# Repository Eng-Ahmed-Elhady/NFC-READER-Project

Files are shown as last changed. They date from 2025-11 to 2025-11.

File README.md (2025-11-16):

🚀 Project Overview – NFC Reader System (Custom 4-Layer Design)

This project was a full hardware development challenge combining power electronics, RF design, embedded control, and EMI/EMC-aware PCB layout.
A special thanks to Altium Academy and Zach — I learned a lot from their content, and it greatly improved the quality of this design.
Proud to say the system is now fully functional, reliable, and ready for integration.














⚡ 1. Power Architecture

The system receives a 24V input and regulates it down efficiently using:

Buck-Boost Converter

Buck Regulator

LDO

Each stage was selected to ensure stable output voltage, low ripple, and clean power delivery to all RF and MCU circuits.

🧠 2. Processing Unit – ESP32

The ESP32 acts as the main controller:

Communicates with the TRF7970A NFC Reader over SPI

Provides external UART interfaces through a dedicated connector

Integrated RESET and BOOT push buttons for convenient programming and debugging

Signal routing and isolation designed for optimal noise immunity

📡 3. NFC / RFID RF Section

A complete RF schematic was designed, including:

Antenna Matching Network

Tuning Circuit

TRF7970A Main RFID Circuit

The RF path was carefully engineered with controlled impedance and proper return-current handling.

🔧 4. External Control & Outputs

The board includes:

Relay driver for controlling an external motor

Input for an external push button

External status LED outputs

Motor activation only occurs after a valid ID is detected

🖥️ PCB Design – 4-Layer Professional Layout

Designed using Altium Designer, following strict high-performance hardware design rules:

Hierarchical schematic structure for clarity and maintenance

Proper track width and spacing for both power and RF routing

Full controlled-impedance profiles, calculated based on the official JLC04161H-3313 stackup

Crystal guard ring with no routing underneath to eliminate EMI coupling

Close placement of decoupling capacitors on every IC power pin

RF ground isolated from power ground, connected at a single defined point

Ground polygon pours and stitching vias to minimize return-current loops

Minimum 3× trace-width spacing between parallel traces to prevent crosstalk

Full compatibility with JLCPCB manufacturing rules and component sourcing from LCSC

All symbols and footprints were created directly from their datasheets

Proper thermal relief and heat-spreading areas for power regulators

Performed comprehensive ERC (Electrical Rule Check) and DRC (Design Rule Check) to ensure the design is error-free and manufacturing-ready

🎯 Final Result

A fully integrated, high-performance NFC Reader offering:
✔ Stable and reliable operation
✔ Clean and accurate RF behavior
✔ Excellent noise immunity
✔ Manufacturing-ready 4-layer layout
✔ Easy integration into larger embedded systems

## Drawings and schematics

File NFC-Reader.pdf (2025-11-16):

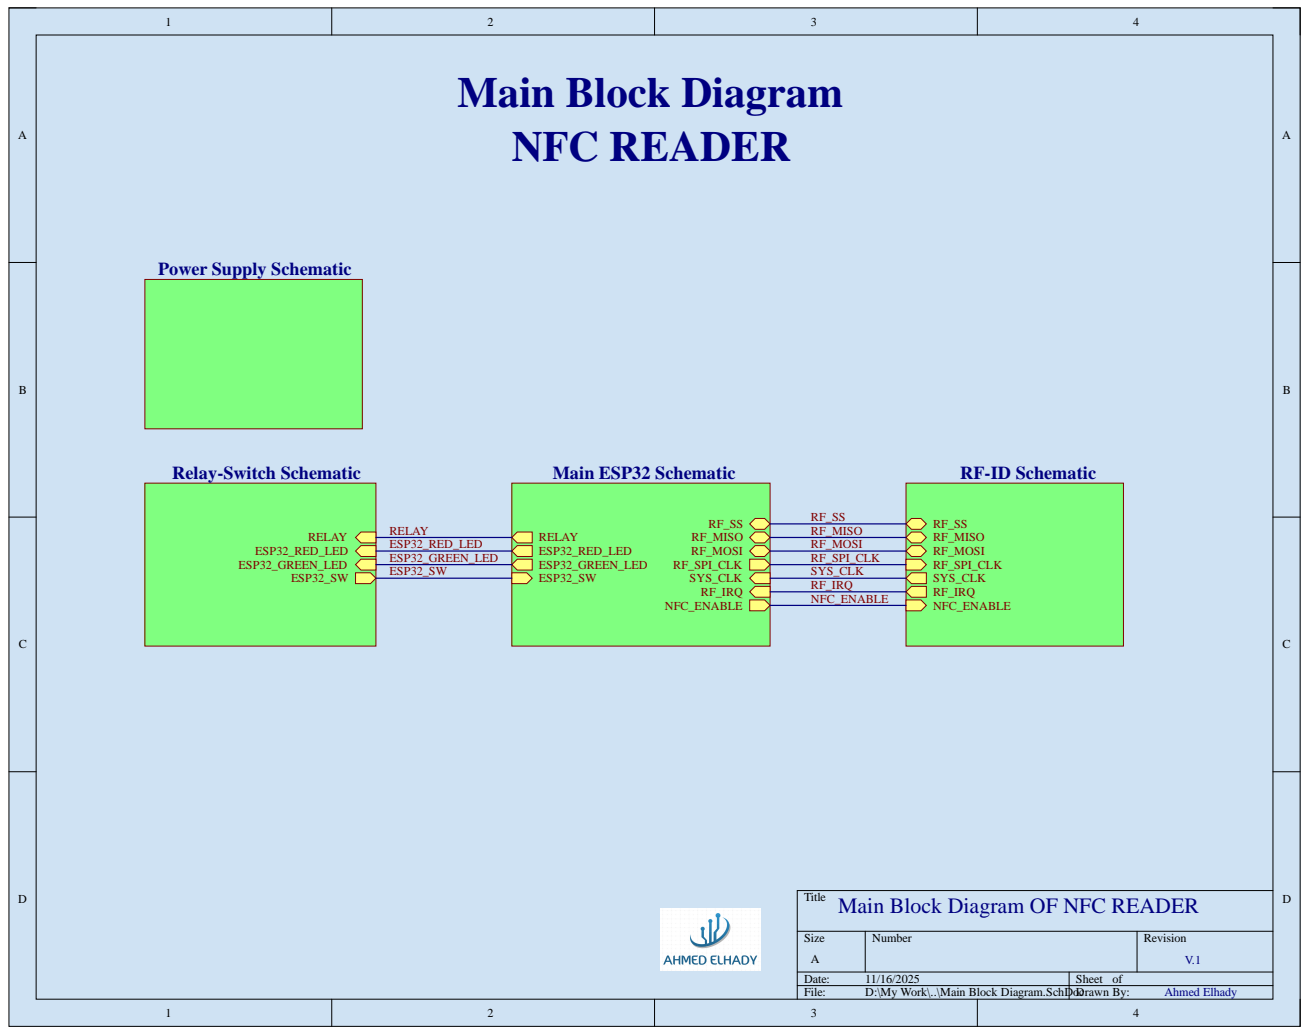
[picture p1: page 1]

E S P32_RE D_L E D | RF_M O S I
E S P32_GRE E N_L E D | RF_S PI_CL K
E S P32_S W | S Y S_CL K

Main Block Diagram OF NFC READER Ahmed

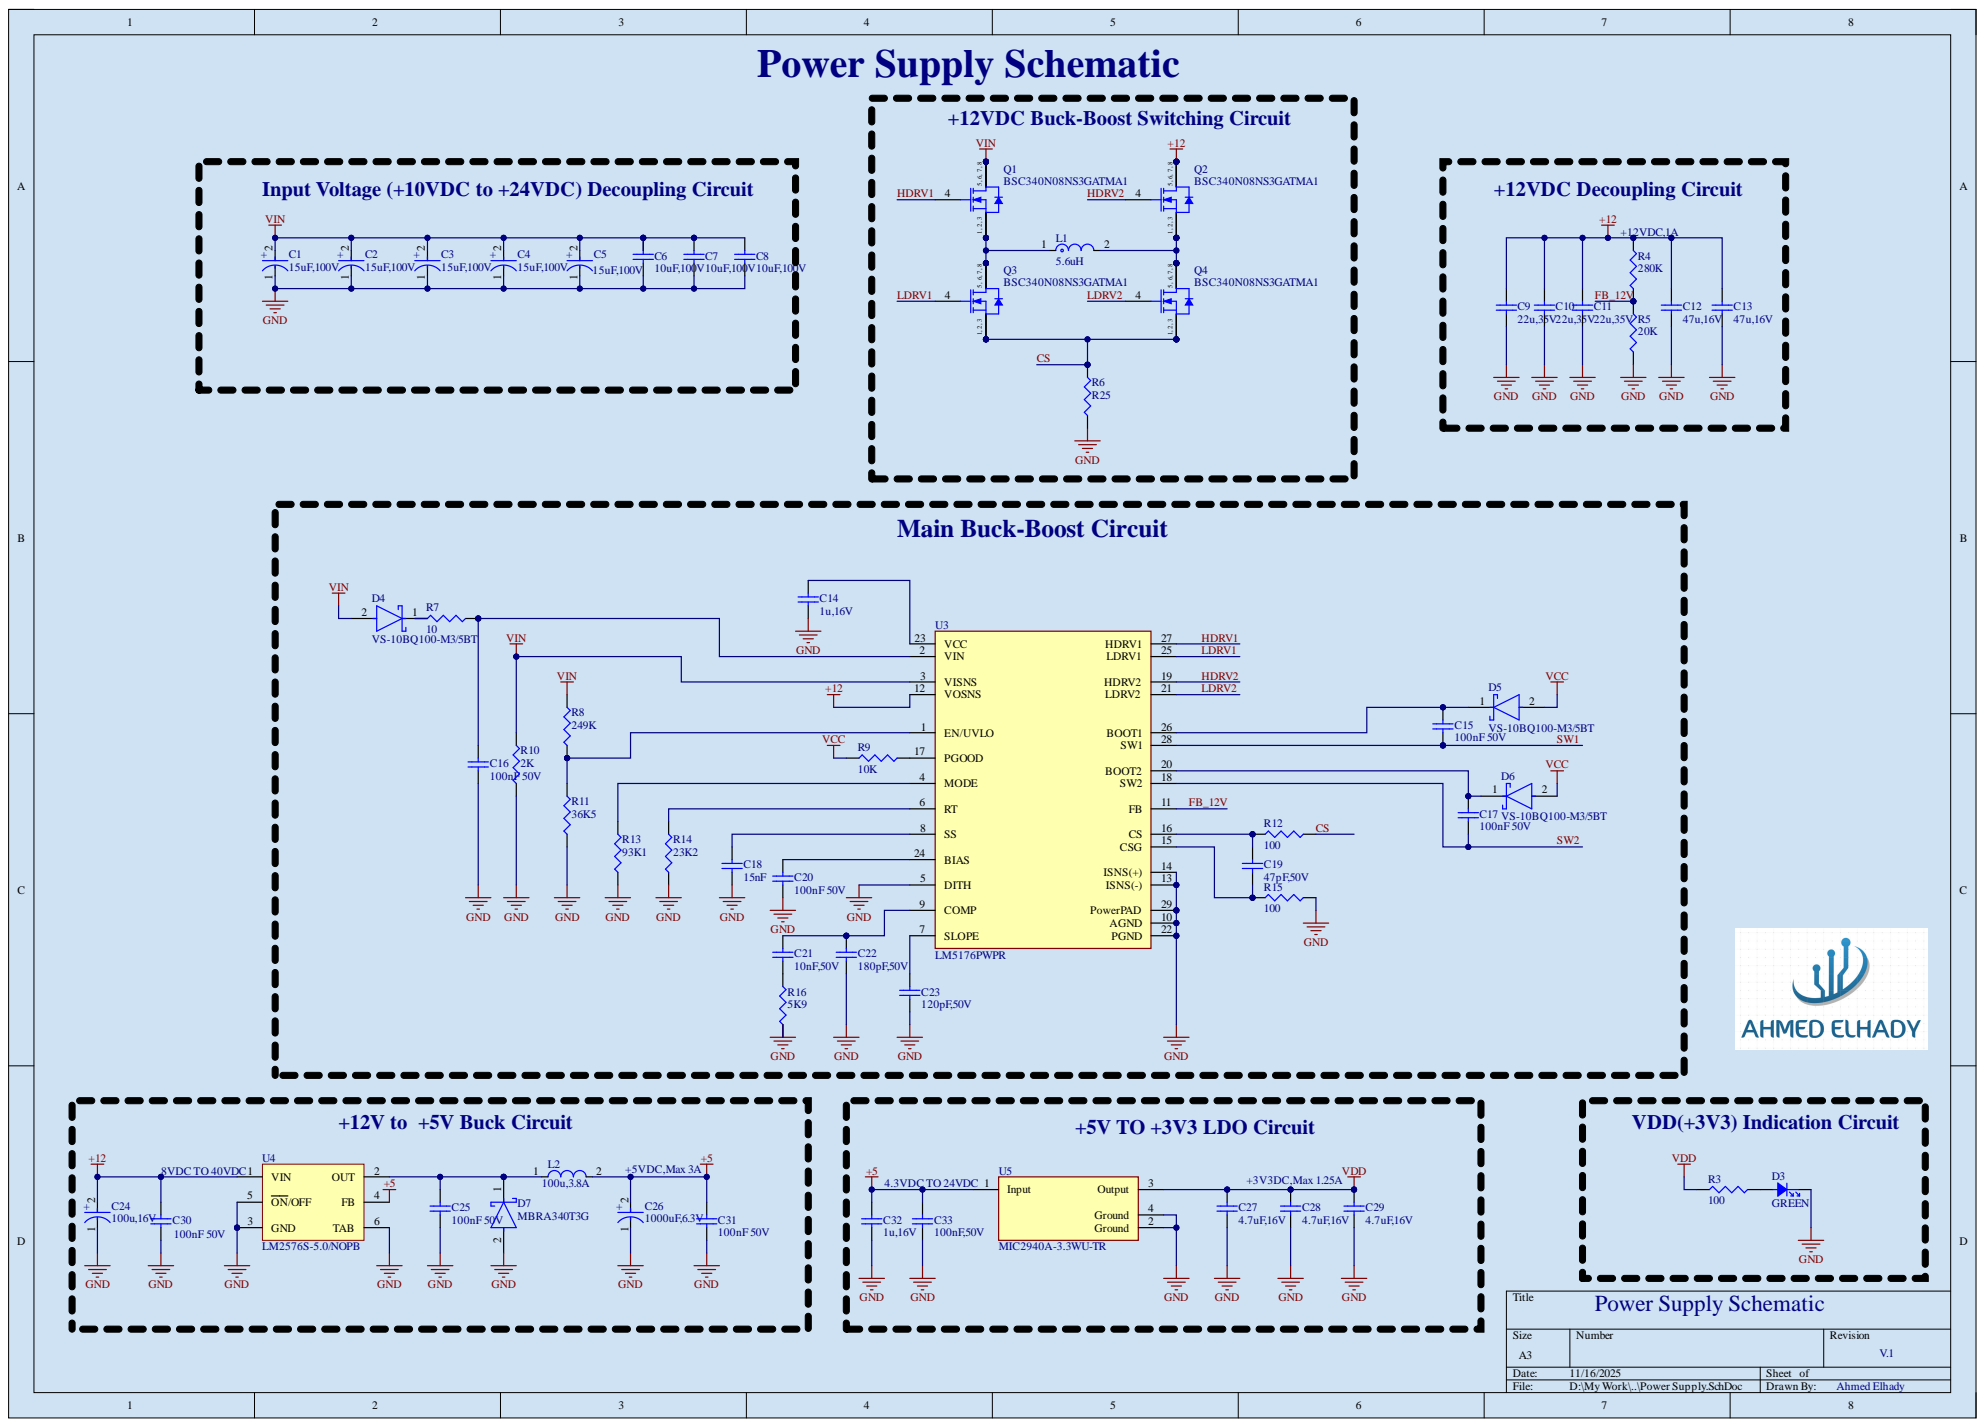
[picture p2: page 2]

+12VDC Buck-Boost Switching Circuit

Main Buck-Boost Circuit

VIN | | VISNS 3
+12 R8 249K | VOSNS 12 | LDRV2

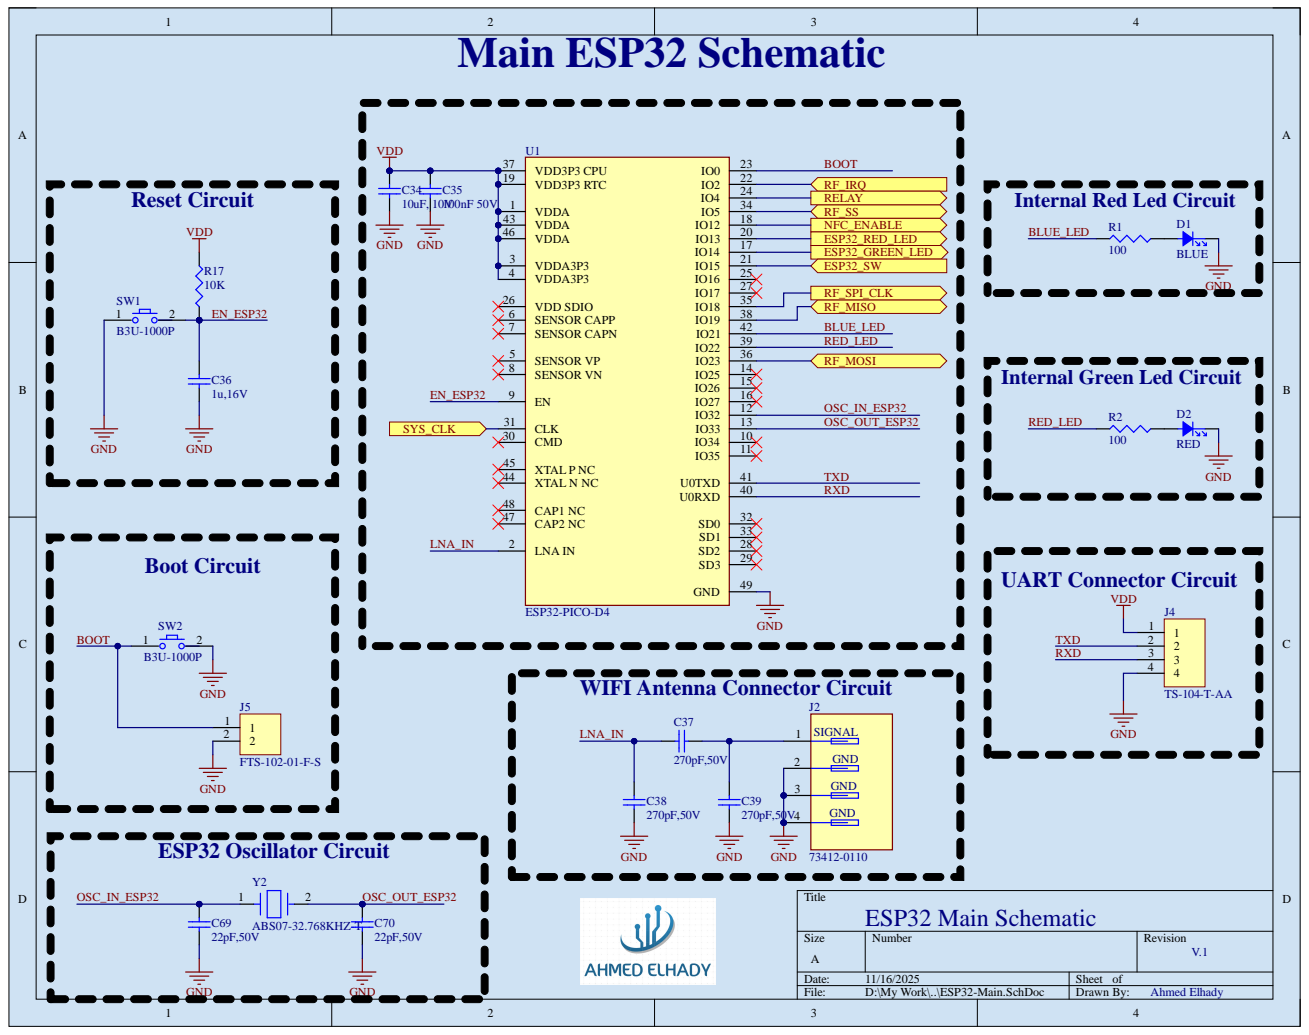
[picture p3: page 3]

Internal Red Led Circuit

Internal Green Led Circuit

WIFI Antenna Connector Circuit

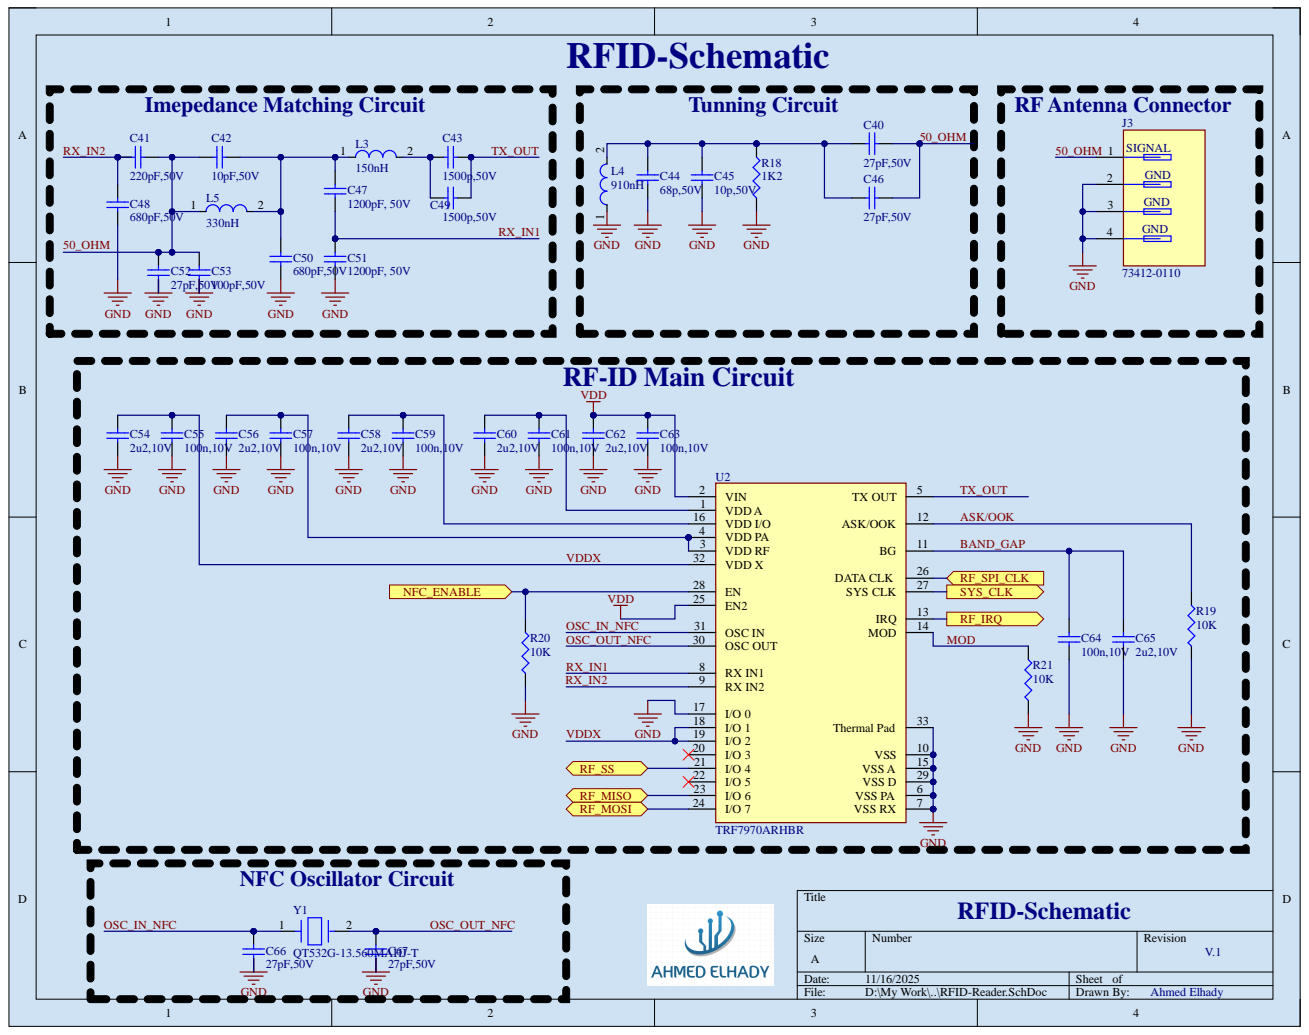
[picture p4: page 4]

RF-ID Main Circuit

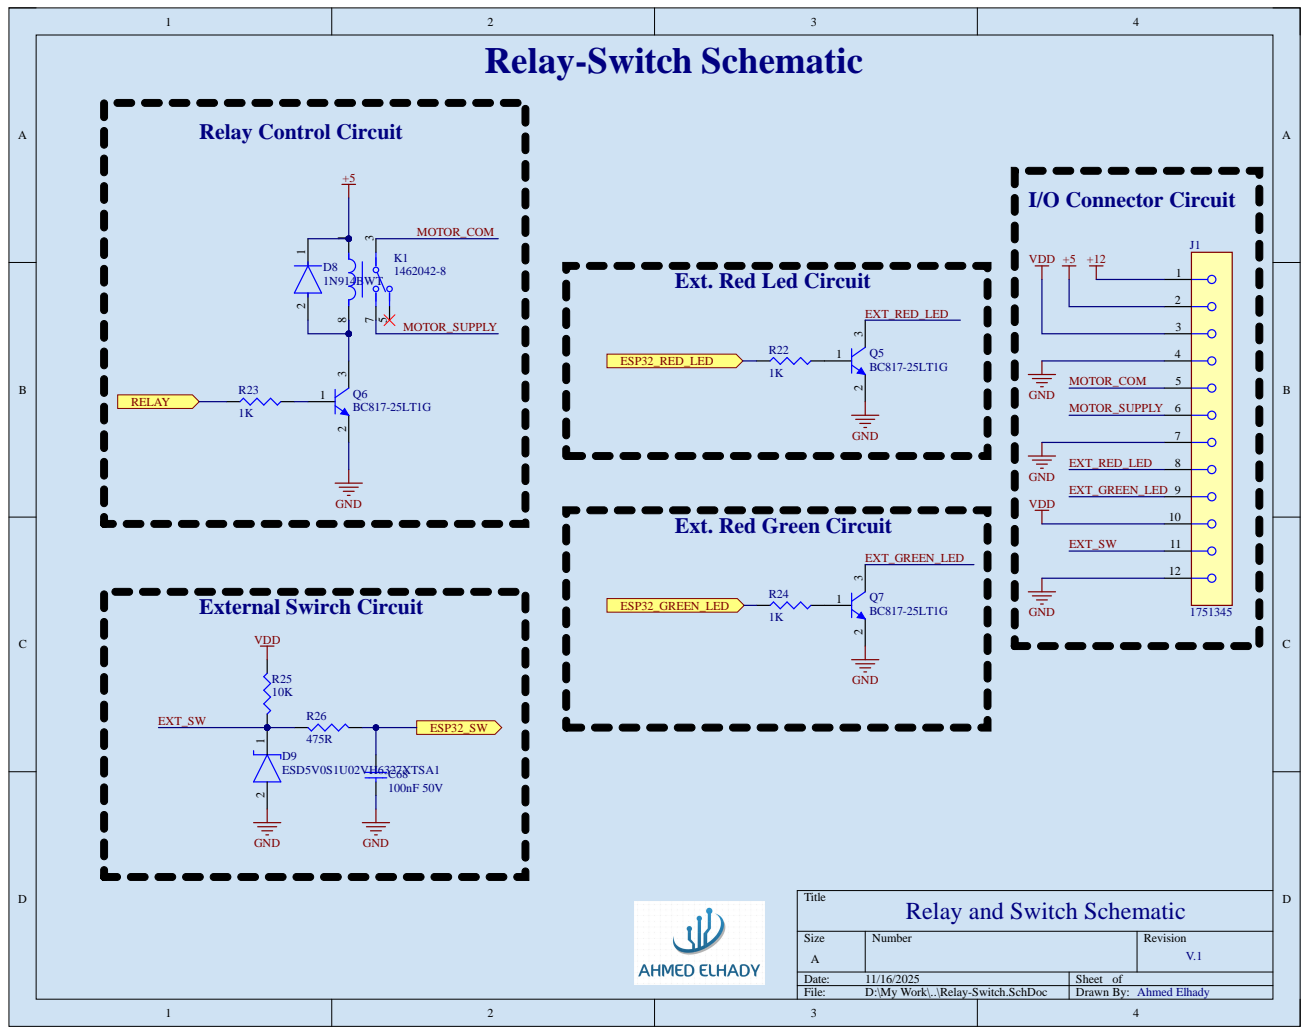
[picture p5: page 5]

Relay-Switch Schematic
I/O Connector Circuit Ahmed Elhady

Ext. Red Led Circuit

Ext. Red Green Circuit

Relay and Switch Schematic

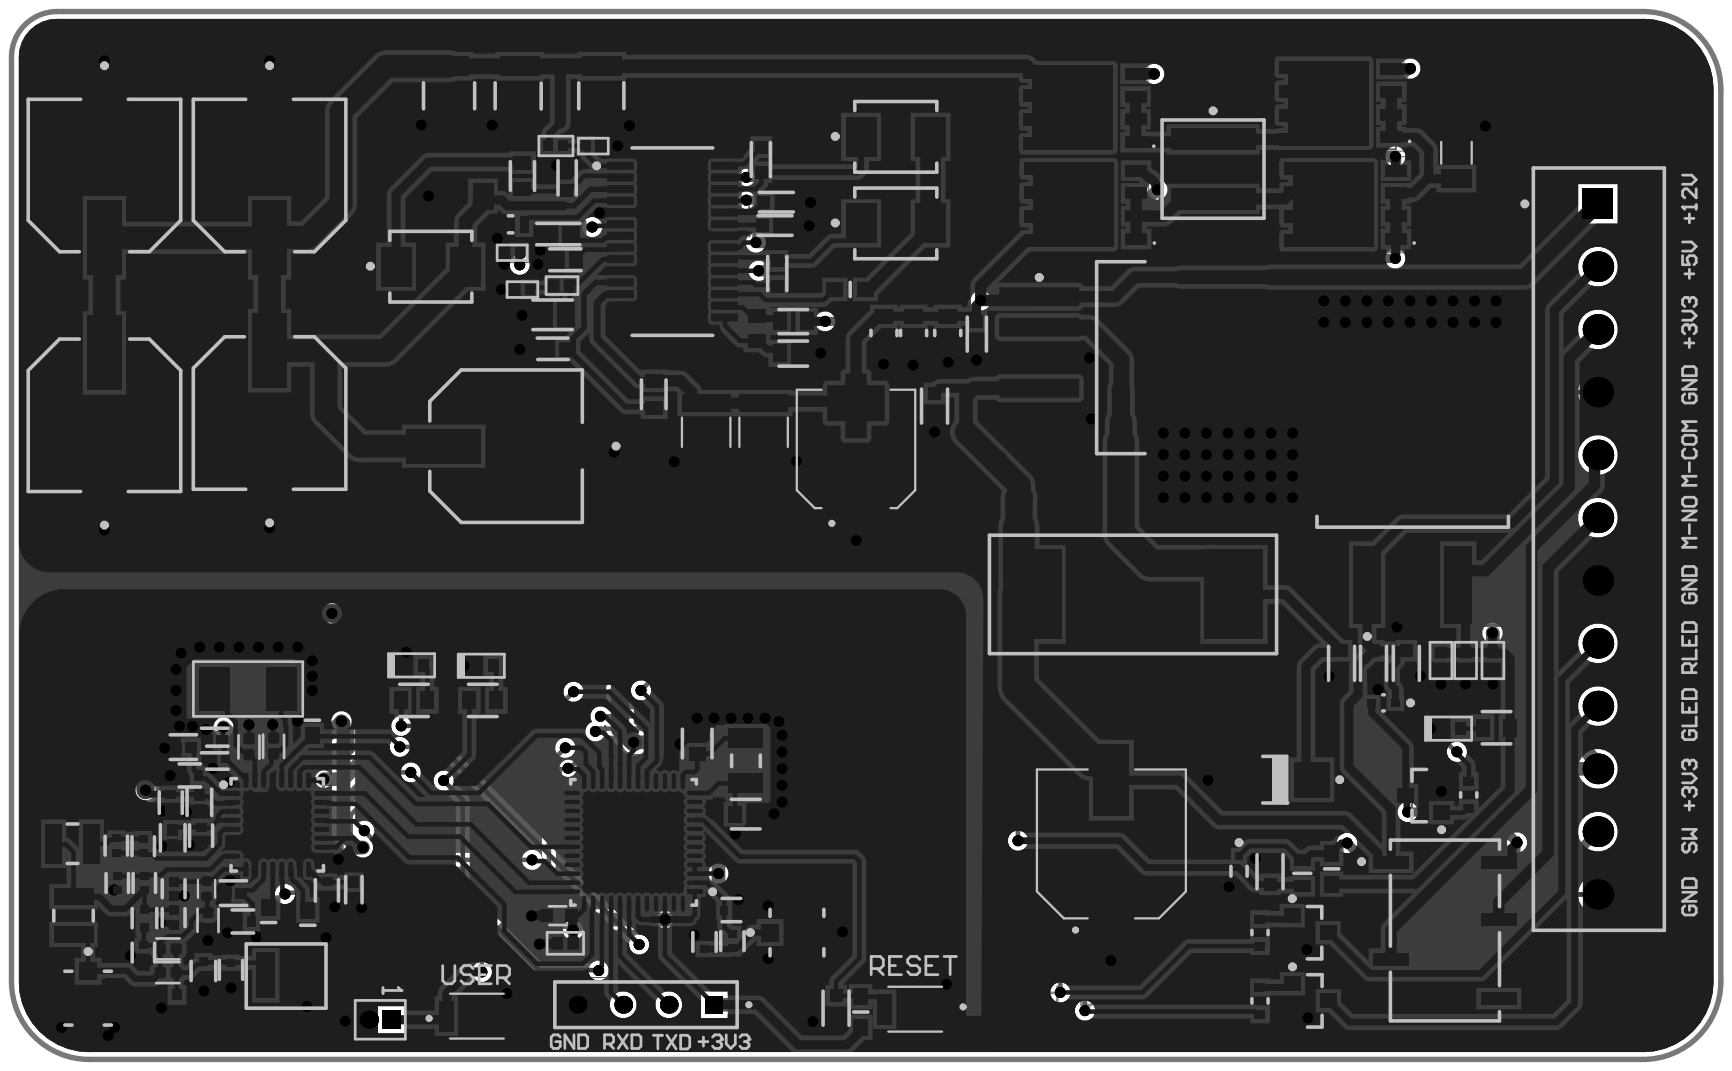
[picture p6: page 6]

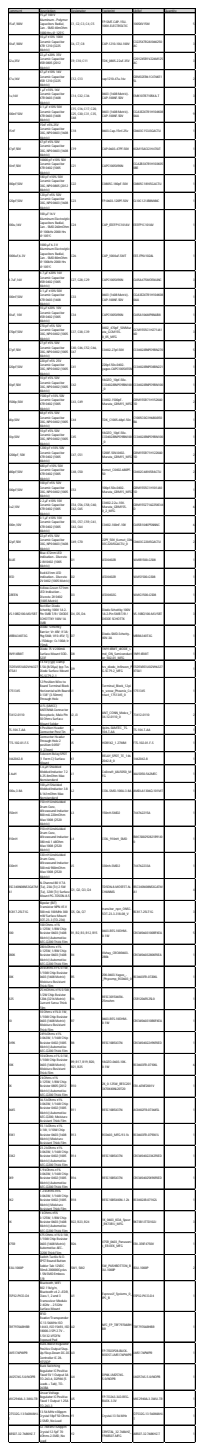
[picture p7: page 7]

10uF,100V | 10 µF ±10% 100V Ceramic Capacitor X7R 1210 (3225 Metric) | C6, C7, C8 | CAP-1210-10U-100V | C3225X7R2A106K250 AC | 3

22u,35V | 22 µF ±20% 35V Ceramic Capacitor X5R 0805 (2012 Metric) | C9, C10, C11 | TDK_0805-22uF-35V | C2012X5R1V226M125 AC | 3

47u,16V | 47 µF ±10% 16V Ceramic Capacitor X5R 1210 (3225 Metric) | C12, C13 | cap1210-47u-16v | GRM32ER61C476KE1 5L | 2

1u,16V | 1 µF ±10% 16V Ceramic Capacitor X7R 0603 (1608 Metric) | C14, C32, C36 | 0603 (1608 Metric)-CAP-100NF-50V | EMK107B7105KA-T | 3

100nF 50V | 0.1 µF ±10% 50V Ceramic Capacitor X7R 0603 (1608 Metric) | C15, C16, C17, C20, C25, C30, C31, C35, C68 | 0603 (1608 Metric)-CAP-100NF-50V | CGA3E2X7R1H104K08 0AA | 9

15nF | 15nF ±5% 25V Ceramic Capacitor C0G, NP0 0603 (1608 Metric) | C18 | 0603-Cap-15nf-25v | C0603C153J3GACTU | 1

47pF,50V | 47 pF ±5% 50V Ceramic Capacitor C0G, NP0 0603 (1608 Metric) | C19 | CAP-0603-47PF-50V | KGM15ACG1H470JT | 1

10nF,50V | 10000 pF ±10% 50V Ceramic Capacitor X7R 0402 (1005 Metric) | C21 | CAPC1005X90N | CGA2B3X7R1H103K05 0BE | 1

180pF,50V | 180 pF ±10% 50V Ceramic Capacitor C0G, NP0 0805 (2012 Metric) | C22 | C0805C-180pF-50V | C0805C181K5GACTU | 1

120pF,50V | 120 pF ±5% 50V Ceramic Capacitor C0G, NP0 0603 (1608 Metric) | C23 | FP-0603-120PF-50V | CL10C121JB8NNNC | 1

100u,16V | 100 µF 16 V Aluminum Electrolytic Capacitors Radial, Can - SMD 260mOhm @ 100kHz 2000 Hrs @ 105°C | C24 | CAP_EEEFP1C101AV | EEEFP1C101AV | 1

1000uF,6.3V | 1000 µF 6.3 V Aluminum Electrolytic Capacitors Radial, Can - SMD 80mOhm @ 100kHz 2000 Hrs @ 105°C | C26 | CAP_1000uF-SMT | EEE-FP0J102AL | 1

4.7uF,16V | 4.7 µF ±20% 16V Ceramic Capacitor X5R 0402 (1005 Metric) | C27, C28, C29 | CAPC1005X90N | CL05A475MO5NUNC | 3

100nF,50V | 0.1 µF ±10% 50V Ceramic Capacitor X7R 0603 (1608 Metric) | C33 | 0603 (1608 Metric)-CAP-100NF-50V | CGA3E2X7R1H104K08 0AA | 1

10uF, 10V | 10 µF ±20% 10V Ceramic Capacitor X5R 0402 (1005 Metric) | C34 | CAPC1005X90N | CL05A106MP8NUB8 | 1

270pF,50V | 270 pF ±5% 50V Ceramic Capacitor C0G, NP0 0402 (1005 Metric) | C37, C38, C39 | 0402_470pF_50VMur ata_GCM155-0_05_MFG | GCM1555C1H271JA1 6D | 3

27pF,50V | 27 pF ±5% 50V Ceramic Capacitor C0G, NP0 0402 (1005 Metric) | C40, C46, C52, C66, C67 | C0402-27pf-50V | CC0402JRNPO9BN270 | 5

220pF,50V | 220 pF ±5% 25V Ceramic Capacitor C0G, NP0 0402 (1005 Metric) | C41 | 220pf-50v-0402-yageo-CAPC1005X55N | CC0402JRNPO8BN221 | 1

10pF,50V | 10 pF ±5% 50V Ceramic Capacitor C0G, NP0 0402 (1005 Metric) | C42 | YAGEO_10pf-50v-CC0402JRNPO9BN100 _0 | CC0402JRNPO9BN100 | 1

1500p,50V | 1500 pF ±10% 50V Ceramic Capacitor X7R 0402 (1005 Metric) | C43, C49 | C0402-1500pF-Murata_GRM15_MFG | GRM155R71H152KA0 1D | 2

68p,50V | 68 pF ±5% 50V Ceramic Capacitor C0G, NP0 0402 (1005 Metric) | C44 | TDK_C1005-68pf-50v | C1005C0G1H680J050 BA | 1

10p,50V | 10 pF ±5% 50V Ceramic Capacitor C0G, NP0 0402 (1005 Metric) | C45 | YAGEO_10pf-50v-CC0402JRNPO9BN100 _0 | CC0402JRNPO9BN100 | 1

1200pF, 50V | 1200 pF ±10% 50V Ceramic Capacitor X7R 0402 (1005 Metric) | C47, C51 | 1200F-50V-0402-Murata_GRM15_MFG | GRM155R71H122KA0 1D | 2

680pF,50V | 680 pF ±10% 50V Ceramic Capacitor X7R 0402 (1005 Metric) | C48, C50 | Kemet_C0402-680PF-50 | C0402C681K5RACTU | 2

100pF,50V | 100 pF ±5% 50V Ceramic Capacitor C0G, NP0 0402 (1005 Metric) | C53 | 100pf-50v-0402-Murata_GRM15_MFG | GRM1555C1H101JA0 1D | 1

2u2,10V | 2.2 µF ±10% 10V Ceramic Capacitor X7R 0402 (1005 Metric) | C54, C56, C58, C60, C62, C65 | C0402-2.2u-10V-Murata_GRM155-0_2_MFG | GRM155Z71A225KE44 D | 6

100n,10V | 0.1 µF ±10% 10V Ceramic Capacitor X7R 0402 (1005 Metric) | C55, C57, C59, C61, C63, C64 | C0402-100nF-10V | CL05B104KP5NNNC | 6

22pF,50V | 22 pF ±5% 50V Ceramic Capacitor C0G, NP0 0603 (1608 Metric) | C69, C70 | 22Pf_50V_Kemet_C06 03C220J5GACTU_0 | C0603C220J5GACTU | 2
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
